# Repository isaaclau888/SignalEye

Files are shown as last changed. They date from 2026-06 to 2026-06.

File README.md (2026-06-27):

# SignalEye
SignalEye_2026-Jun-18_06-48-48AM-000_CustomizedView6057489903_png

Imagine living in a flat with a security guard downstairs, but a thief can still come to your flat, steal your stuff and run away (This is not my situation, just an imagination only; it's fake). To prevent this kind of thing from happening, you MUST have SignalEye, your home guardian; it lets you check who is outside your door.    

## What's it for?
It's for home safety. It prevents burglary from happening. With a Smart Doorbell, you can know who comes to your home.

## How to build it?

Please print all the 3D parts and buy all the parts from the BOM list. <p>
螢幕截圖 2026-06-18 下午4 03 06

# BOM
| | | | | | | | | | | | |
|---|---|----|---|---|---|---|---|---|---|---|---|
| | | | | | | | | | | | |
| |Description |Item|Usage Count|Purchase Quantity|Unit Price|Subtotal|Price(HKD) [$]|Price(RMB) [$]|Price(USD) [$]|Link |Additional description|
| |Electrical Components | | | | | | | | | | |
| |ESP32-CAM with camera + ESP32-CAM-MB + Cable | |1 |1 |$66.06 |$66.06  |$66.06 |$56.99 |$8.43 |https://detail.tmall.com/item.htm?id=995997275127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 | |
| |Male-to-Female Dupont Jumper Wires (20cm) | |1 |1 |$3.89 |$3.89 |$3.89 |$3.36 |$0.50 |https://item.taobao.com/item.htm?id=740182471156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 | |
| |Lever Wire Connectors (1-in 1-out) | |1 |1 |$5.56 |$5.56 |$5.56 |$4.80 |$0.71 |https://detail.tmall.com/item.htm?id=772853735770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| |
| |12mm Waterproof Metal Push Button with Wired Socket (3-8V, Self-Resetting, Ring LED + Pre-wired socket plug)| |1 |1 |$6.95 |$6.95 |$6.95 |$6.00 |$0.89 |https://item.taobao.com/item.htm?id=726059425167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 | |
| |18650 lithium battery with Smart Charger (Two 5550mWh pointed-tip batteries [with smart charger]) | |1 |1 |$30.14 |$30.14  |$30.14 |$26.00 |$3.85 |https://detail.tmall.com/item.htm?id=680644058705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 | |
| |ESP32 18650 lithium battery expansion board (Single-slot shield) | |1 |1 |$6.38 |$6.38 |$6.38 |$5.50 |$0.81 |https://item.taobao.com/item.htm?id=632816781540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 | |
| | | | | |Total | |$118.98 |$102.65 |$15.19 | | |

# 3D Parts Assembly
First, place the bottom part. <p>
螢幕截圖 2026-06-18 下午4 04 05

Secondly, place the ESP32-CAM with the camera, ESP32-CAM-MB, which connects the cable to the 18650 lithium battery expansion board with one 18650 lithium battery inside the bottom case. <p>
螢幕截圖 2026-06-18 下午4 06 01

Thirdly, connect the connectors. <p>
螢幕截圖 2026-06-18 下午4 14 36

Last but not least, place the top part on top. <p>
螢幕截圖 2026-06-18 下午4 15 33

# Wiring Diagram
SignalEye Wiring Diagram

Just follow the diagram. <p>
Use a green jumper wire to connect IO12 on the Burner Base -> Connects to Green (NO) on the button <p>
Use a green jumper wire to connect GND on the Burner Base -> Connects to the other Green (NO) on the button <p>
Use a red jumper wire to connect 3V3 on the Burner Base -> Connects to Red (+) on the button <p>
Use a black jumper wire to connect GND on the Burner Base -> Connects to Black (-) on the button <p>
And for the power supply, connect the USB-C part of the wire to the ESP32-CAM-MB, connect the USB-A part of the wire to the 18650 lithium battery expansion board, which has one 18650 lithium battery inside. <p>
If you need another 18650 lithium battery, you must charge it with a charger and connect it like that. <p>

## How can you use it?
1. Install Arduino IDE:
Download and install the latest Arduino IDE from the official Arduino website.
2. Install ESP32 Board Core:
Open Arduino IDE and go to File > Preferences. 
In the Additional Boards Manager URLs field, paste this URL: 
https://espressif.github.io/arduino-esp32/package_esp32_index.json 
Click OK.
Go to Tools > Board > Boards Manager, search for ESP32, and click Install.
3. Select Your Board and Port:
Go to Tools > Board > ESP32 and select AI Thinker ESP32-CAM.
Plug your black burner programming base into your computer via a USB cable.
Go to Tools > Port and select the correct port for your connected board.
4. Upload the Code:
Load your complete SignalEye.ino code into the workspace.
Update the Wi-Fi SSID, password, and your personal Slack webhook path lines inside the script.
Click the Upload arrow button in the top-left corner. After a few seconds, it will finish uploading!
5. Fire It Up:
Open your Serial Monitor (Tools > Serial Monitor), set the speed to 115200 baud, and press the physical Reset button on your board. Watch your smart doorbell connect to the network and trigger your first Slack alert! Yay!!!

## Why did I make it?
I decided to make this because I want to keep my home safe; I don't want random people knocking on my door.

## How I made it?
I used Fusion 360 to make the snap-fit case, Arduino IDE for the coding part and last but not least, the parts from the BOM.

# Fallout Zine 


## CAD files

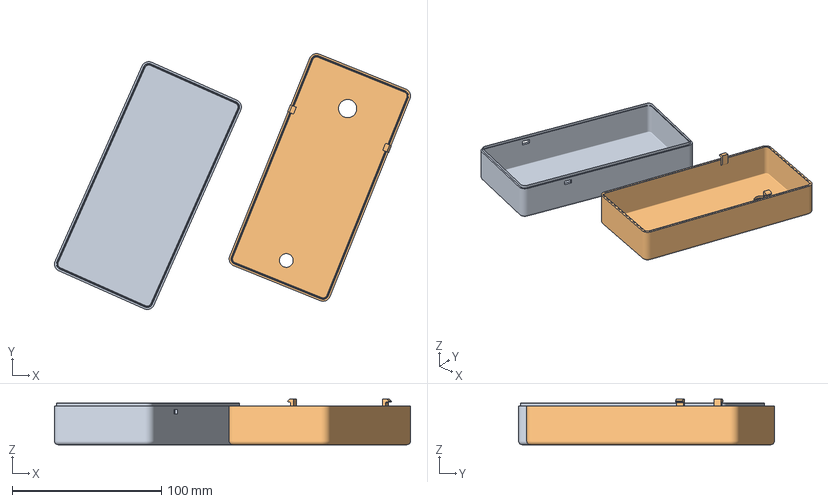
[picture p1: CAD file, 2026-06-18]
SignalEye 3mf File/SignalEye.3mf
238.6 x 171.5 x 30.5 mm
SignalEye Bottom.step
SignalEye Top.step

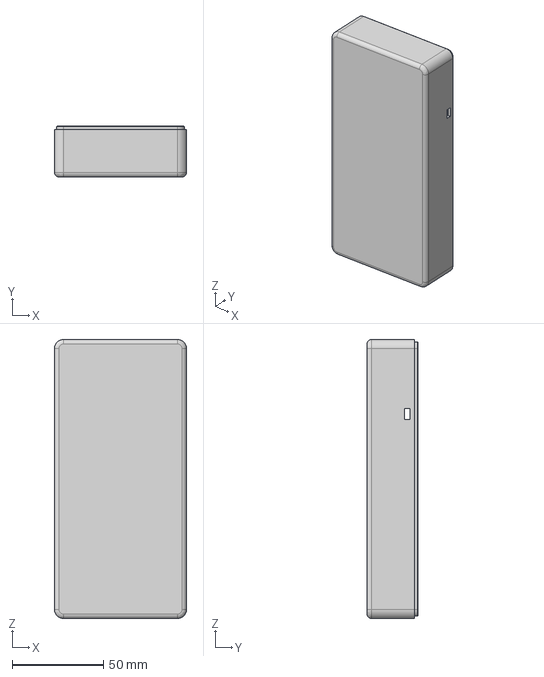
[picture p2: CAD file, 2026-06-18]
SignalEye STEP Files/SignalEye Bottom.step
72.5 x 28.0 x 153.0 mm

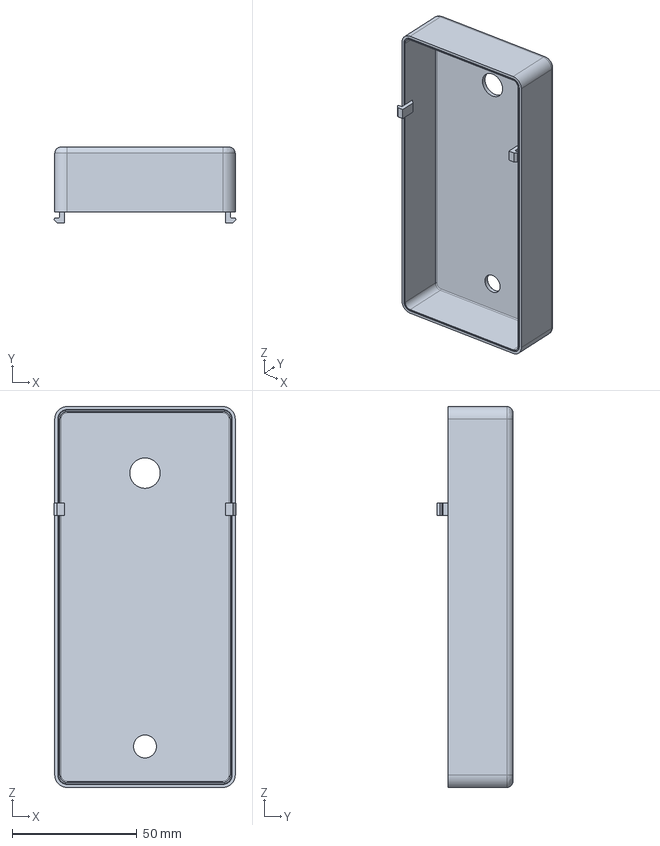
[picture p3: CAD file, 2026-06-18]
SignalEye STEP Files/SignalEye Top.step
73.1 x 30.5 x 153.0 mm

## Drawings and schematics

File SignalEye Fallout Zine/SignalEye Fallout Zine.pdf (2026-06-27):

# SignalEye

# Your Home Guardian

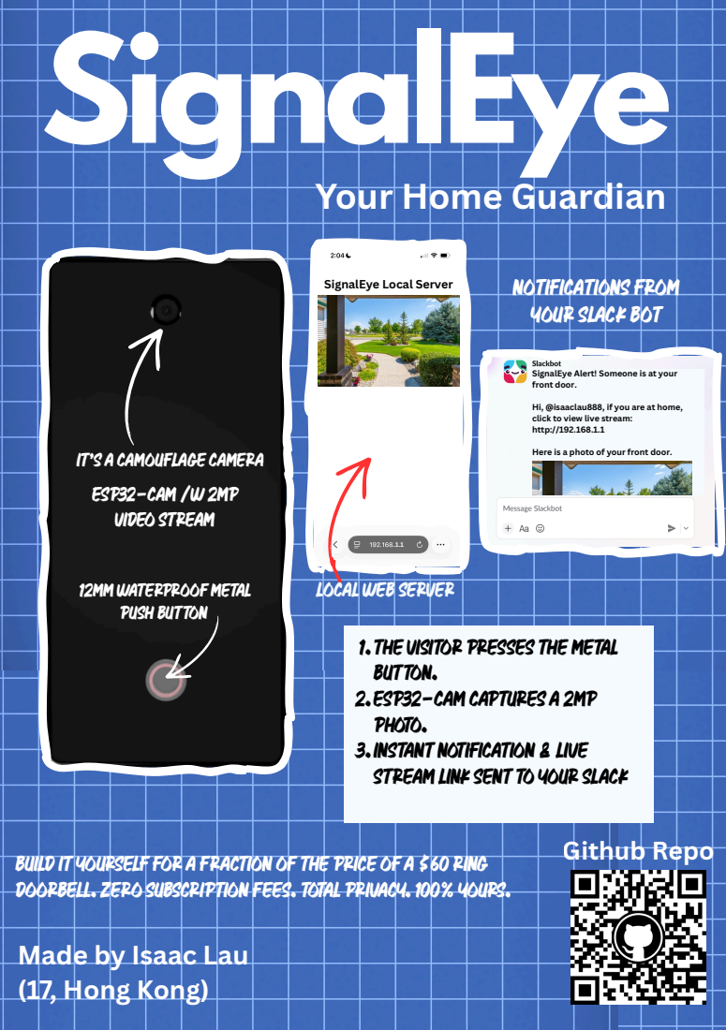
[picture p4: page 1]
Github Repo; 12mm Waterproof Metal Push Button

Notifications from
.1.1 SignalEye Local Server

your Slack Bot

SignalEye Alert! Someone is at your
front door.

Hi, @isaaclau888, if you are at home,
click to view live stream:
http://192.168.1.1

Here is a photo of your front door.

It’s a camouflage camera
ESP32-CAM /w 2MP
Video Stream

Local Web Server

1.The visitor presses the metal
button.
2.ESP32-CAM captures a 2MP
photo.
3.Instant notification & live
stream link sent to your Slack

BUILD IT YOURSELF FOR A FRACTION OF THE PRICE OF A $60 RING
DOORBELL. ZERO SUBSCRIPTION FEES. TOTAL PRIVACY. 100% YOURS.

Made by Isaac Lau
(17, Hong Kong)

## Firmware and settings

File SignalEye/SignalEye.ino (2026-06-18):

#include "esp_camera.h"
#include <WiFi.h>
#include <WiFiClientSecure.h>
#include "esp_http_server.h"

const char* ssid = "YOUR_WIFI_SSID";
const char* password = "YOUR_WIFI_PASSWORD";

const char* slack_path = "/services/YOUR/WEBHOOK/PATH/HERE";
const char* slack_host = "hooks.slack.com";

const unsigned long AWAKE_TIMEOUT = 120000; 
unsigned long wakeStartTime = 0;

#define PWDN_GPIO_NUM     32
#define RESET_GPIO_NUM    -1
#define XCLK_GPIO_NUM      0
#define SIOD_GPIO_NUM     26
#define SIOC_GPIO_NUM     27
#define Y9_GPIO_NUM       35
#define Y8_GPIO_NUM       34
#define Y7_GPIO_NUM       39
#define Y6_GPIO_NUM       36
#define Y5_GPIO_NUM       21
#define Y4_GPIO_NUM       19
#define Y3_GPIO_NUM       18
#define Y2_GPIO_NUM        5
#define VSYNC_GPIO_NUM     25
#define HREF_GPIO_NUM      23
#define PCLK_GPIO_NUM      22

#define PART_BOUNDARY "123456789000000000000987654321"
static const char* _STREAM_CONTENT_TYPE = "multipart/x-mixed-replace;boundary=" PART_BOUNDARY;
static const char* _STREAM_BOUNDY = "\r\n--" PART_BOUNDARY "\r\n";
static const char* _STREAM_PART = "Content-Type: image/jpeg\r\nContent-Length: %u\r\n\r\n";

httpd_handle_t stream_httpd = NULL;

static esp_err_t stream_handler(httpd_req_t *req){
  camera_fb_t * fb = NULL;
  esp_err_t res = ESP_OK;
  size_t _jpg_buf_len = 0;
  uint8_t * _jpg_buf = NULL;
  char * part_buf[64];

  res = httpd_resp_set_type(req, _STREAM_CONTENT_TYPE);
  if(res != ESP_OK) return res;

  while(true){
    fb = esp_camera_fb_get();
    if (!fb) {
      Serial.println("Camera capture failed");
      res = ESP_FAIL;
    } else {
      _jpg_buf_len = fb->len;
      _jpg_buf = fb->buf;
    }
    if(res == ESP_OK){
      size_t hlen = snprintf((char *)part_buf, 64, _STREAM_PART, _jpg_buf_len);
      res = httpd_resp_send_chunk(req, (const char *)part_buf, hlen);
    }
    if(res == ESP_OK){
      res = httpd_resp_send_chunk(req, (const char *)_jpg_buf, _jpg_buf_len);
    }
    if(res == ESP_OK){
      res = httpd_resp_send_chunk(req, _STREAM_BOUNDY, strlen(_STREAM_BOUNDY));
    }
    if(fb){
      esp_camera_fb_return(fb);
      fb = NULL;
      _jpg_buf = NULL;
    }
    if(res != ESP_OK) break;
  }
  return res;
}

void startCameraServer(){
  httpd_config_t config = HTTPD_DEFAULT_CONFIG();
  config.server_port = 80;

  httpd_uri_t stream_uri = {
    .uri       = "/",
    .method    = HTTP_GET,
    .handler   = stream_handler,
    .user_ctx  = NULL
  };
  
  if (httpd_start(&stream_httpd, &config) == ESP_OK) {
    httpd_register_uri_handler(stream_httpd, &stream_uri);
    Serial.println("Stream Server running.");
  }
}

void sendSlackMessage(String ipAddress) {
  WiFiClientSecure client;
  client.setInsecure(); 
  
  Serial.println("Connecting to Slack...");
  if (!client.connect(slack_host, 443)) {
    Serial.println("Slack connection failed.");
    return;
  }

  String message = "*SignalEye Alert!* Someone is at your front door.\n";
  message += "If you are at home, click to view live stream: http://" + ipAddress;
  
  String payload = "{\"text\": \"" + message + "\"}";

  client.print(String("POST ") + slack_path + " HTTP/1.1\r\n" +
               "Host: " + slack_host + "\r\n" +
               "Content-Type: application/json\r\n" +
               "Content-Length: " + String(payload.length()) + "\r\n" +
               "Connection: close\r\n\r\n" +
               payload);

  Serial.println("Slack message dispatched!");
}

void setup() {
  Serial.begin(115200);
  wakeStartTime = millis(); 
  
  pinMode(GPIO_NUM_12, INPUT_PULLUP);
  esp_sleep_enable_ext0_wakeup(GPIO_NUM_12, 0); 

  camera_config_t config;
  config.ledc_channel = LEDC_CHANNEL_0;
  config.ledc_timer = LEDC_TIMER_0;
  config.pin_d0 = Y2_GPIO_NUM;
  config.pin_d1 = Y3_GPIO_NUM;
  config.pin_d2 = Y4_GPIO_NUM;
  config.pin_d3 = Y5_GPIO_NUM;
  config.pin_d4 = Y6_GPIO_NUM;
  config.pin_d5 = Y7_GPIO_NUM;
  config.pin_d6 = Y8_GPIO_NUM;
  config.pin_d7 = Y9_GPIO_NUM;
  config.pin_xclk = XCLK_GPIO_NUM;
  config.pin_pclk = PCLK_GPIO_NUM;
  config.pin_vsync = VSYNC_GPIO_NUM;
  config.pin_href = HREF_GPIO_NUM;
  config.pin_sscb_sda = SIOD_GPIO_NUM;
  config.pin_sscb_scl = SIOC_GPIO_NUM;
  config.pin_pwdn = PWDN_GPIO_NUM;
  config.pin_reset = RESET_GPIO_NUM;
  config.xclk_freq_hz = 20000000;
  config.pixel_format = PIXFORMAT_JPEG; 

  config.frame_size = FRAMESIZE_VGA; 
  config.jpeg_quality = 10;          
  config.fb_count = 2;               

  esp_err_t err = esp_camera_init(&config);
  if (err != ESP_OK) {
    Serial.printf("Camera init failed: 0x%x\n", err);
    return;
  }

  WiFi.begin(ssid, password);
  Serial.print("Connecting to Wi-Fi");
  unsigned long startAttempt = millis();
  while (WiFi.status() != WL_CONNECTED && millis() - startAttempt < 10000) {
    delay(500);
    Serial.print(".");
  }

  if (WiFi.status() == WL_CONNECTED) {
    String localIP = WiFi.localIP().toString();
    Serial.println("\nWi-Fi Connected!");
    
    startCameraServer(); 
    sendSlackMessage(localIP);
  } else {
    Serial.println("\nWi-Fi Timeout. Sleeping.");
    esp_deep_sleep_start();
  }
}

void loop() {
  if (millis() - wakeStartTime >= AWAKE_TIMEOUT) {
    Serial.println("\nTime's up! Entering deep sleep mode... Zzz");
    delay(1000);
    esp_deep_sleep_start();
  }
  delay(1000);
}
